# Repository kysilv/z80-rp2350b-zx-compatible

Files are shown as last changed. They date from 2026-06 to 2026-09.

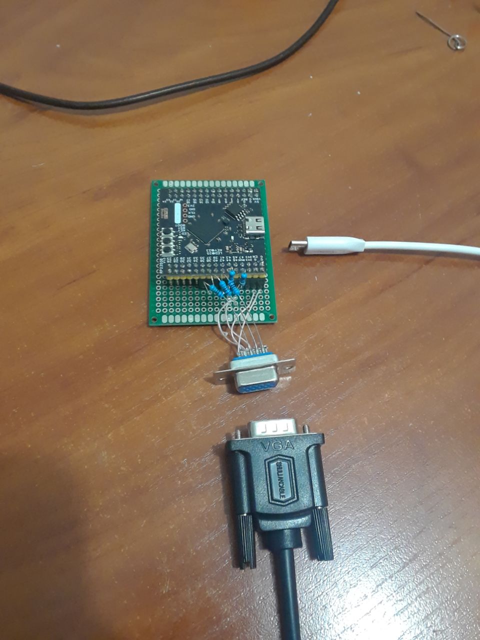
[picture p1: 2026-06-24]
photos/vga_test.jpg

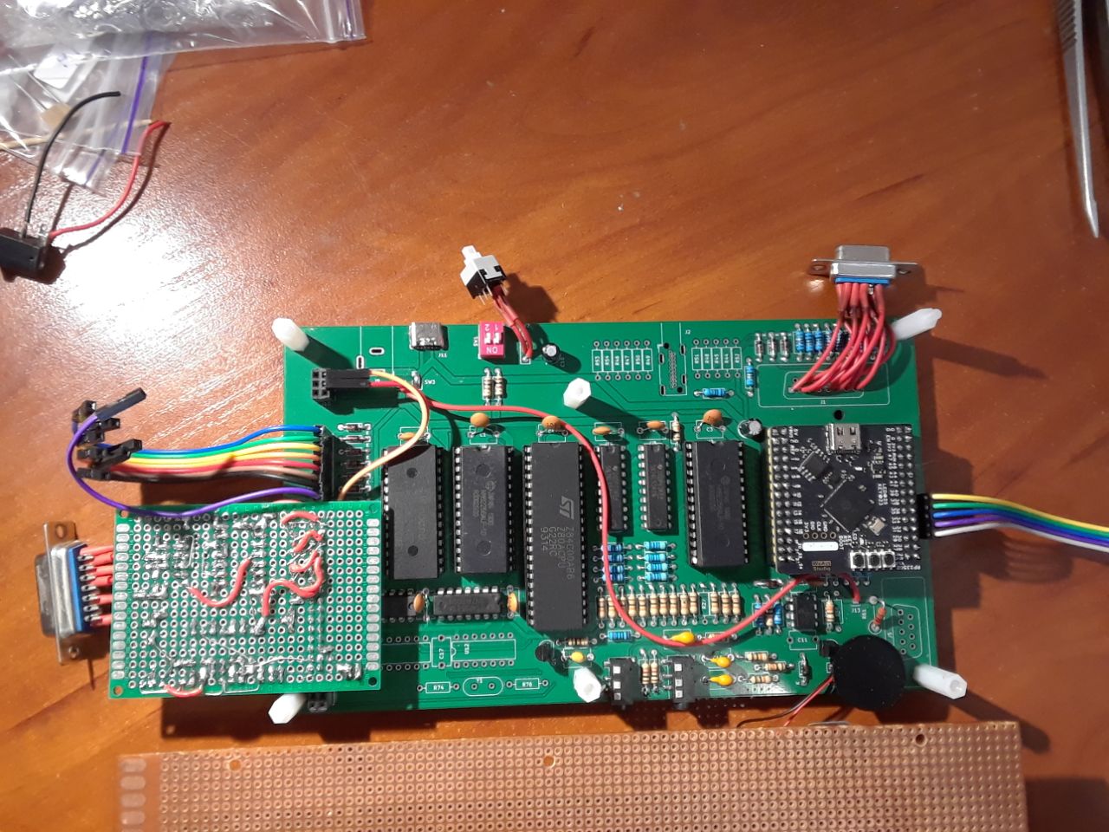
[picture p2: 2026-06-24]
photos/9_Joystick_da15_installed.jpg

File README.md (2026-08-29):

# z80-rp2350b-zx-compatible
This is a retrocomputer compatible with ZX Spectrum and based on real Z80 + discrete RAM/ROM + rp2350b to cover ULA functionality programmatically.

## Specification:

**CPU**: Z84C00AB6 Z80A CPU DIP-40

**ROM**: W27c512-45z DIP-28

**RAM**: 2xHM62256ALP-10 DIP-28

**ULA**: WeAct RP2350B Core board

**Video**: VGA (DE-15) and DVI over HDMI connector, 720x576p emulating Spectrum PAL resolution.

**Audio**: Speaker on board

**Cassette interface**: Jack 3.5mm for smartphone headset jack

**Keyboard**: Handmade

**Joystick**: 
  1. Retro DA-15 GamePort joystick interface connected to expansion connector, emulating Kempston port 1F.
  2. Sinclair Joystick 1 in parallel to keyboard 6-0 (connector not soldered yet).

## Folders:

**firmware**: Source code for rp2350b covering ULA functionality (C + PIO ASM)

**hardware**: Pictures of schematic and pcbs, KiCAD projects of the computer and Joystick interface. There are pictures of the first version with a lot of fixes. 

**photos**: Photos of the device in process of tuning and some "screenshots".

Press: https://hackaday.com/2026/07/13/its-a-spectrum-with-an-rp2350-ula/

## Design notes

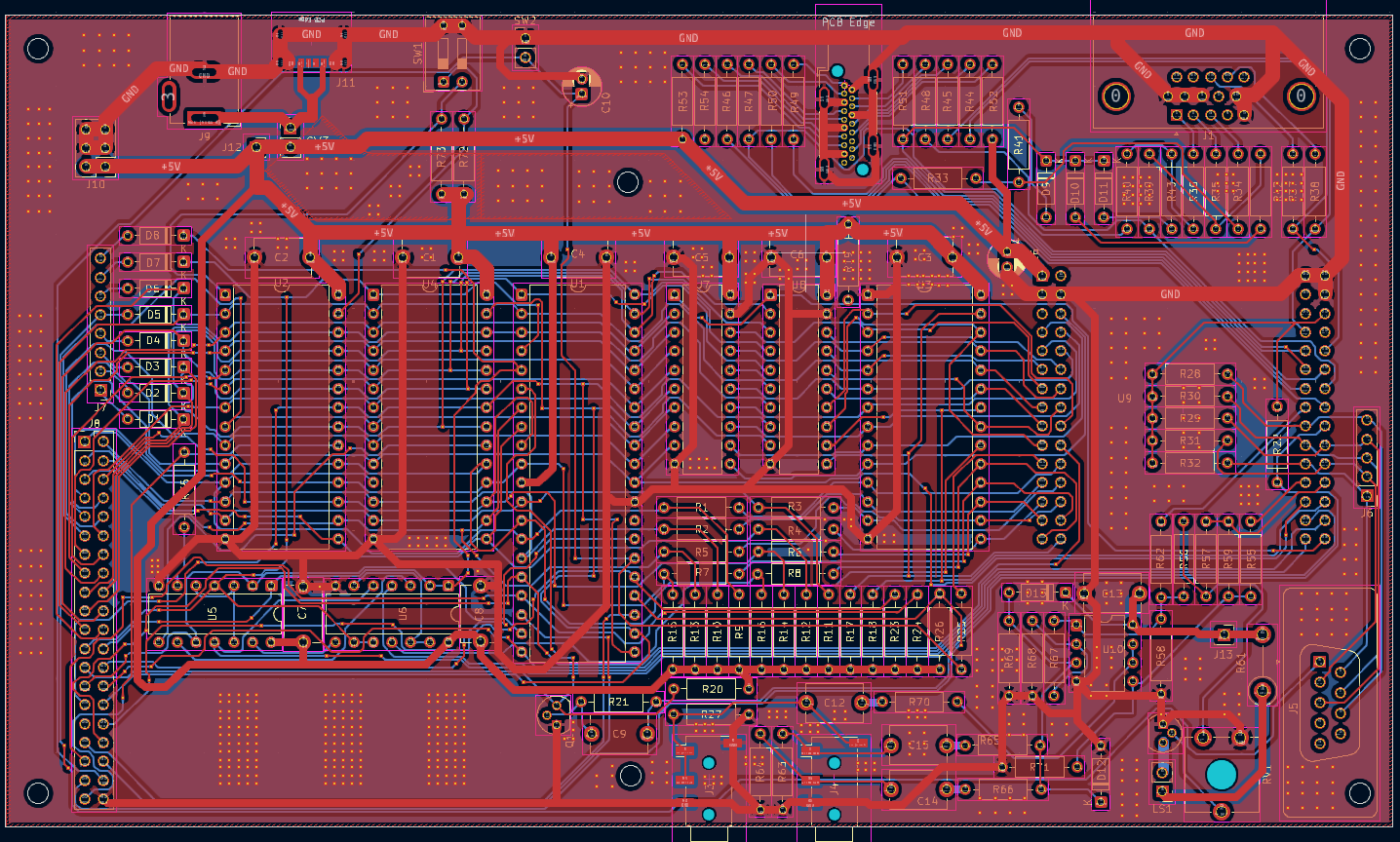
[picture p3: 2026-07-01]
hardware/3_5_pcb_new.png

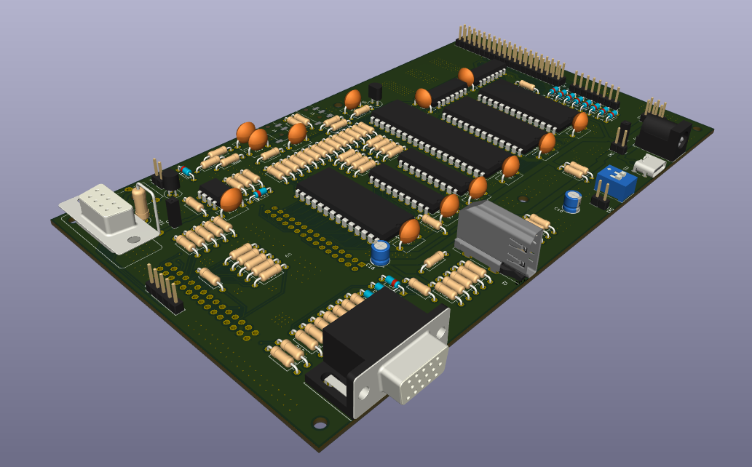
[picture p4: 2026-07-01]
hardware/3_6_3d_View.png

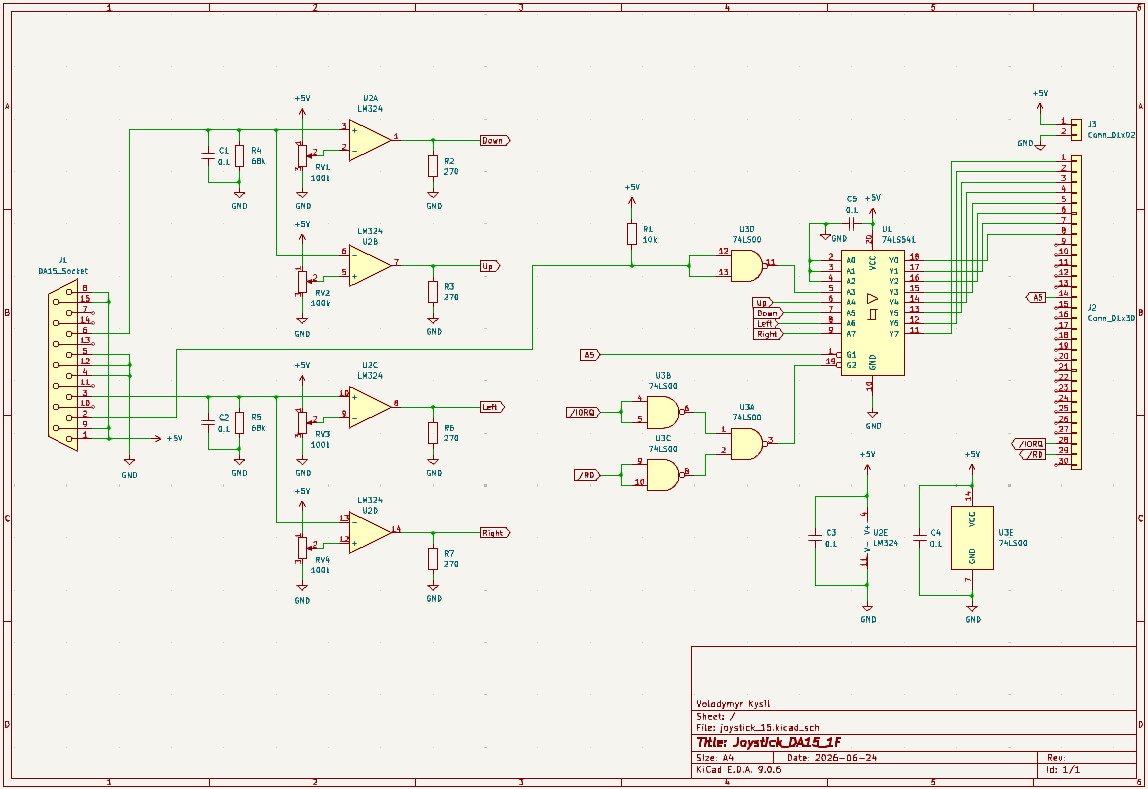
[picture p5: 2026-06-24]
hardware/4_Joystick_DA15_1F_schematic.png

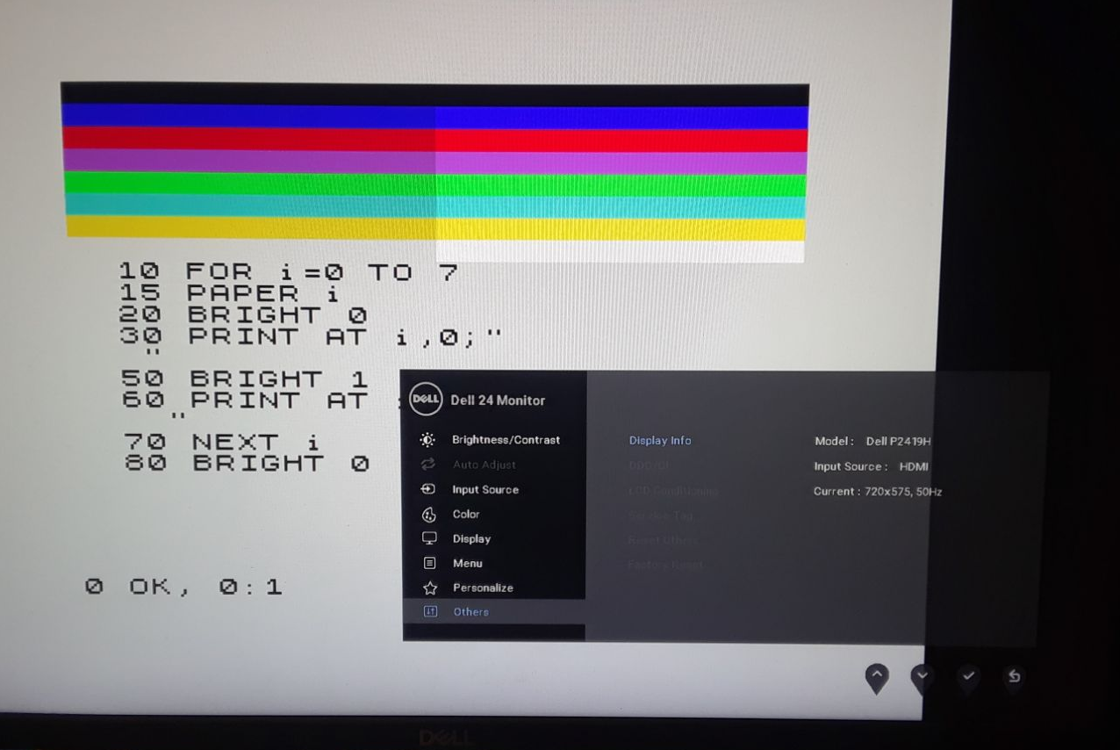
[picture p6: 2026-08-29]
hardware/7_HDMI_colors.png

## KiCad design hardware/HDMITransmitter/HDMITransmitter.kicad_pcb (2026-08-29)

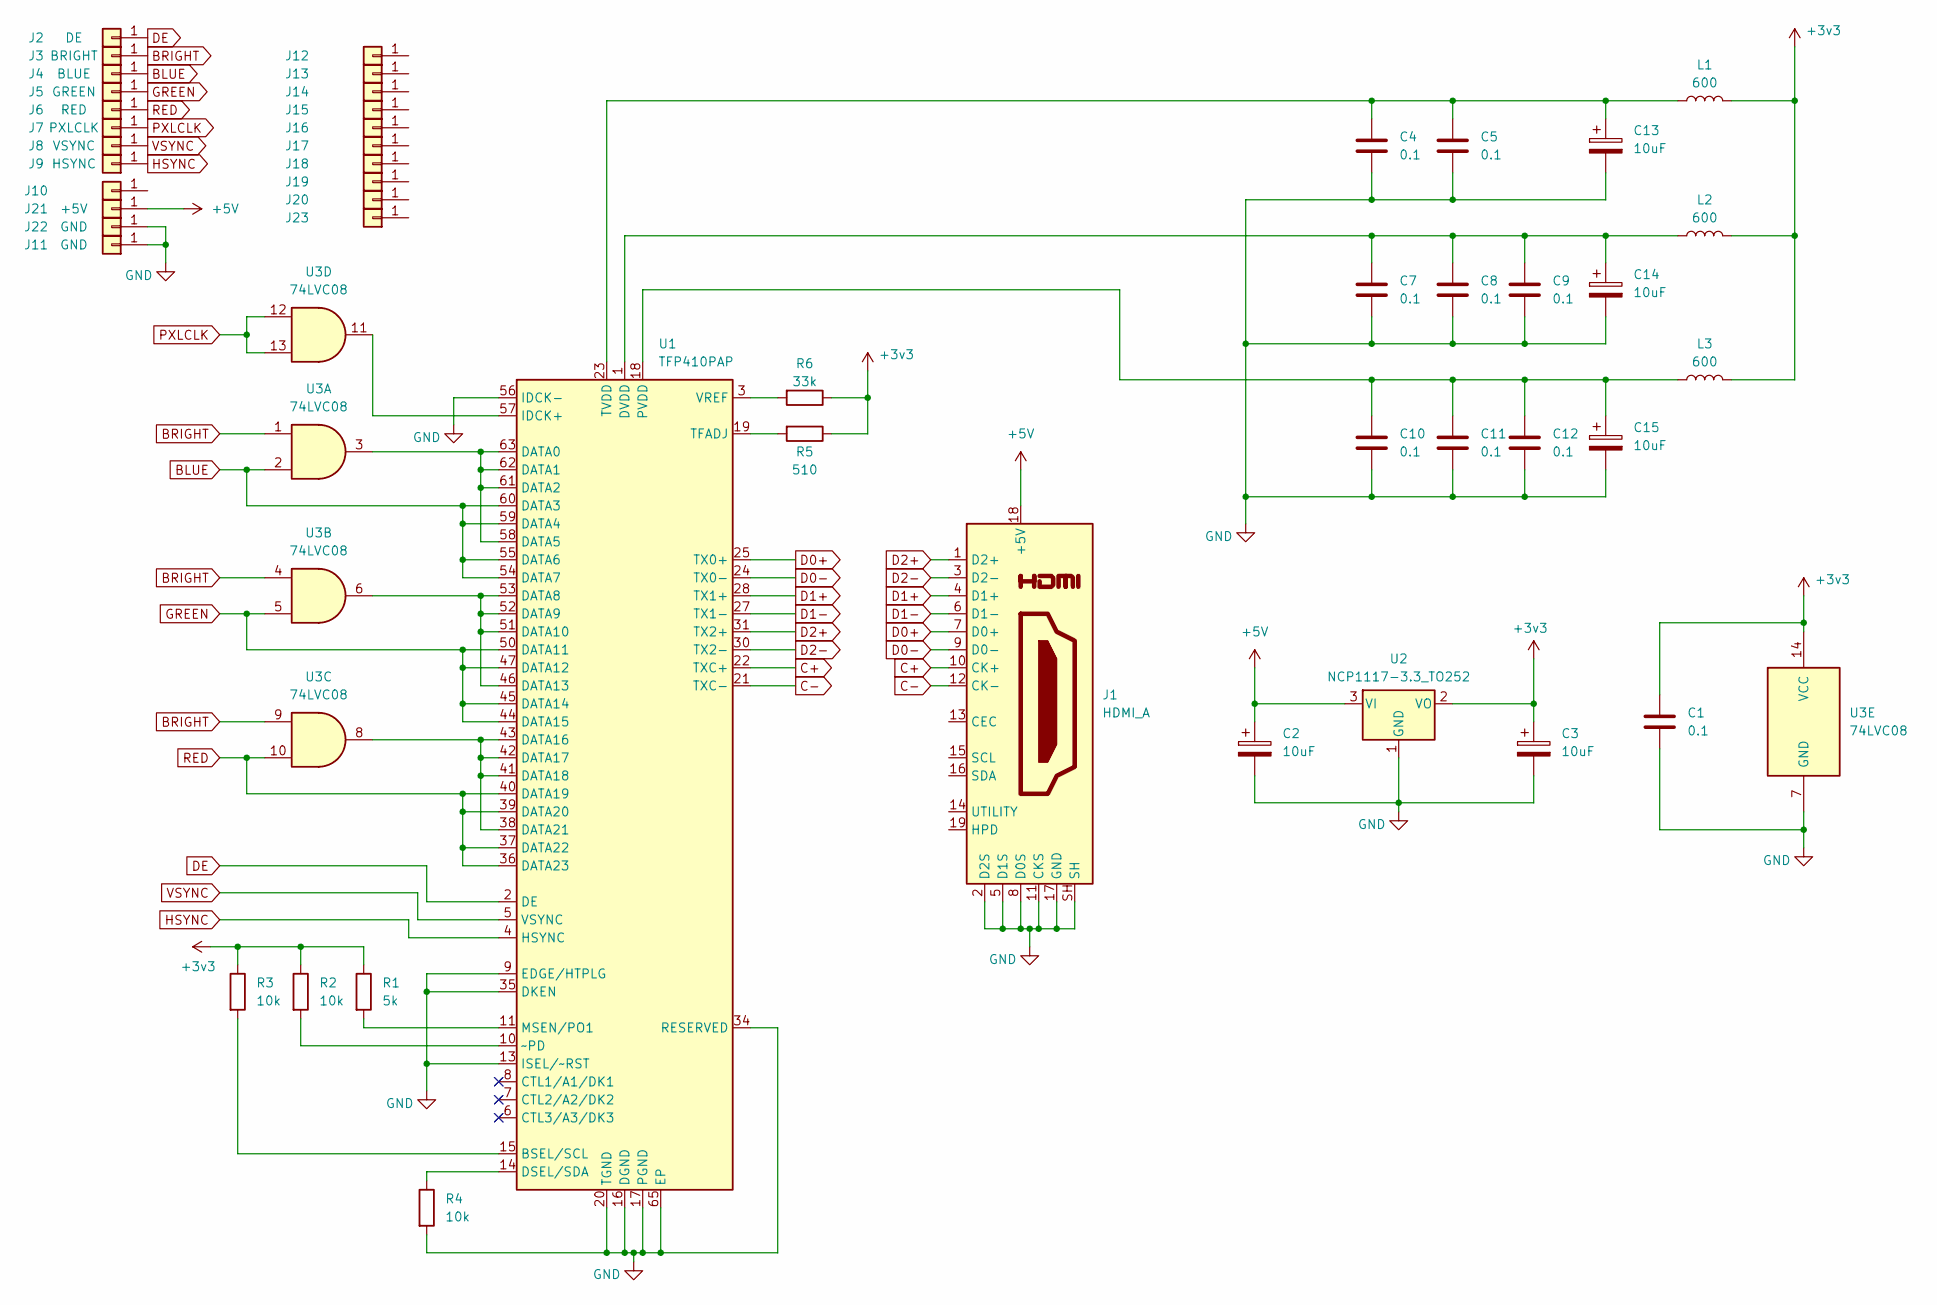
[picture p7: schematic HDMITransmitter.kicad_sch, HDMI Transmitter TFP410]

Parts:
C1, C4, C5, C7, C8, C9, C10, C11, C12: 0.1; C_0603_1608Metric_Pad1.08x0.95mm_HandSolder
C2, C3, C13, C14, C15: 10uF; CP_EIA-3216-18_Kemet-A_HandSolder
J1: HDMI_A; HDMI_A_Molex_208658-1001_Horizontal
J2: DE; Pin_D1.0mm_L10.0mm
J3: BRIGHT; Pin_D1.0mm_L10.0mm
J4: BLUE; Pin_D1.0mm_L10.0mm
J5: GREEN; Pin_D1.0mm_L10.0mm
J6: RED; Pin_D1.0mm_L10.0mm
J7: PXLCLK; Pin_D1.0mm_L10.0mm
J8: VSYNC; Pin_D1.0mm_L10.0mm
J9: HSYNC; Pin_D1.0mm_L10.0mm
J10, J12, J13, J14, J15, J16, J17, J18, J19, J20, J23: Pin_D1.0mm_L10.0mm
J11, J22: GND; Pin_D1.0mm_L10.0mm
J21: +5V; Pin_D1.0mm_L10.0mm
L1, L2, L3: 600; L_0603_1608Metric_Pad1.05x0.95mm_HandSolder
R1: 5k; R_0603_1608Metric_Pad0.98x0.95mm_HandSolder
R2, R3, R4: 10k; R_0603_1608Metric_Pad0.98x0.95mm_HandSolder
R5: 510; R_0603_1608Metric_Pad0.98x0.95mm_HandSolder
R6: 33k; R_0603_1608Metric_Pad0.98x0.95mm_HandSolder
U1: TFP410PAP; Texas_TQFP-64-1EP_10x10mm_P0.5mm_EP8x8mm_Mask5x5mm_ThermalV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
U2: NCP1117-3.3_TO252; TO-252-2
U3: 74LVC08; SOIC-14_3.9x8.7mm_P1.27mm

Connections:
+3v3: C1.1, C3.1, L1.2, L2.2, L3.2, R1.1, R2.1, R3.1, R5.1, R6.1, U2.2 (VO), U3.14 (VCC)
+5V: C2.1, J1.18 (+5V), J21.1, U2.3 (VI)
BLUE: J4.1, U1.54 (DATA7), U1.55 (DATA6), U1.59 (DATA4), U1.60 (DATA3), U3.2
BRIGHT: J3.1, U3.1, U3.4, U3.9
C+: J1.10 (CK+), U1.22 (TXC+)
C-: J1.12 (CK-), U1.21 (TXC-)
D0+: J1.7 (D0+), U1.25 (TX0+)
D0-: J1.9 (D0-), U1.24 (TX0-)
D1+: J1.4 (D1+), U1.28 (TX1+)
D1-: J1.6 (D1-), U1.27 (TX1-)
D2+: J1.1 (D2+), U1.31 (TX2+)
D2-: J1.3 (D2-), U1.30 (TX2-)
DE: J2.1, U1.2 (DE)
GND: C1.2, C2.2, C3.2, C4.2, C5.2, C7.2, C8.2, C9.2, C10.2, C11.2, C12.2, C13.2, C14.2, C15.2, J1.2 (D2S), J1.5 (D1S), J1.8 (D0S), J1.11 (CKS), J1.17 (GND), J1.SH, J11.1, J22.1, R4.2, U1.9 (EDGE/HTPLG), U1.13 (ISEL/~RST), U1.16 (DGND), U1.17 (PGND), U1.20 (TGND), U1.26 (TGND), U1.32 (TGND), U1.34 (RESERVED), U1.35 (DKEN), U1.48 (DGND), U1.56 (IDCK-), U1.64 (DGND), U1.65 (EP), U2.1 (GND), U3.7 (GND)
GREEN: J5.1, U1.44 (DATA15), U1.45 (DATA14), U1.47 (DATA12), U1.50 (DATA11), U3.5
HSYNC: J9.1, U1.4 (HSYNC)
unnamed: C4.1, C5.1, C13.1, L1.1, U1.23 (TVDD), U1.29 (TVDD)
unnamed: C7.1, C8.1, C9.1, C14.1, L2.1, U1.1 (DVDD), U1.12 (DVDD), U1.33 (DVDD)
unnamed: R3.2, U1.15 (BSEL/SCL)
unnamed: U1.58 (DATA5), U1.61 (DATA2), U1.62 (DATA1), U1.63 (DATA0), U3.3
unnamed: U1.46 (DATA13), U1.51 (DATA10), U1.52 (DATA9), U1.53 (DATA8), U3.6
unnamed: U1.38 (DATA21), U1.41 (DATA18), U1.42 (DATA17), U1.43 (DATA16), U3.8
unnamed: R4.1, U1.14 (DSEL/SDA)
unnamed: U1.57 (IDCK+), U3.11
unnamed: R1.2, U1.11 (MSEN/PO1)
unnamed: C10.1, C11.1, C12.1, C15.1, L3.1, U1.18 (PVDD)
unnamed: R5.2, U1.19 (TFADJ)
unnamed: R6.2, U1.3 (VREF)
unnamed: R2.2, U1.10 (~PD)
PXLCLK: J7.1, U3.12, U3.13
RED: J6.1, U1.36 (DATA23), U1.37 (DATA22), U1.39 (DATA20), U1.40 (DATA19), U3.10
VSYNC: J8.1, U1.5 (VSYNC)

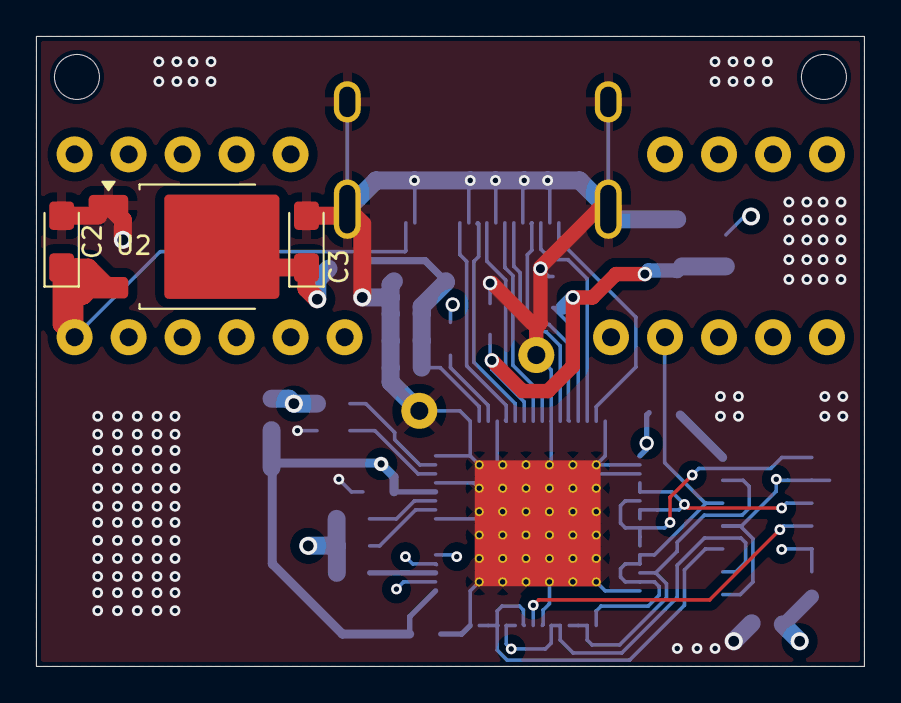
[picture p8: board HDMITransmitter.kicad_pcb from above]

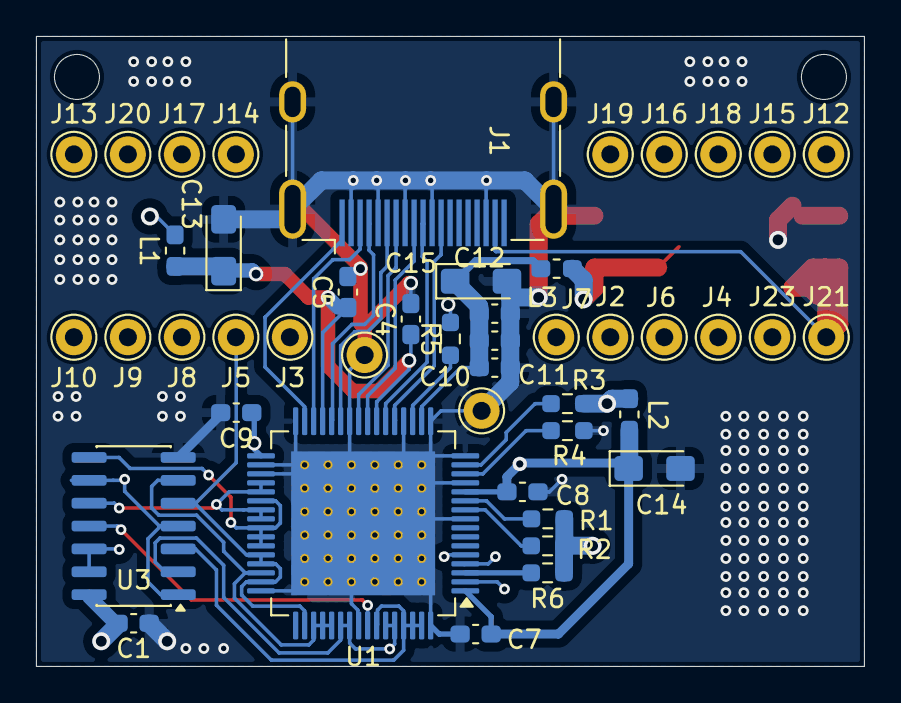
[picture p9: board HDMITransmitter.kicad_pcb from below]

Board: 4 copper layers, 46.0 x 35.0 mm, 49 parts (46 on the bottom side), 32 nets.

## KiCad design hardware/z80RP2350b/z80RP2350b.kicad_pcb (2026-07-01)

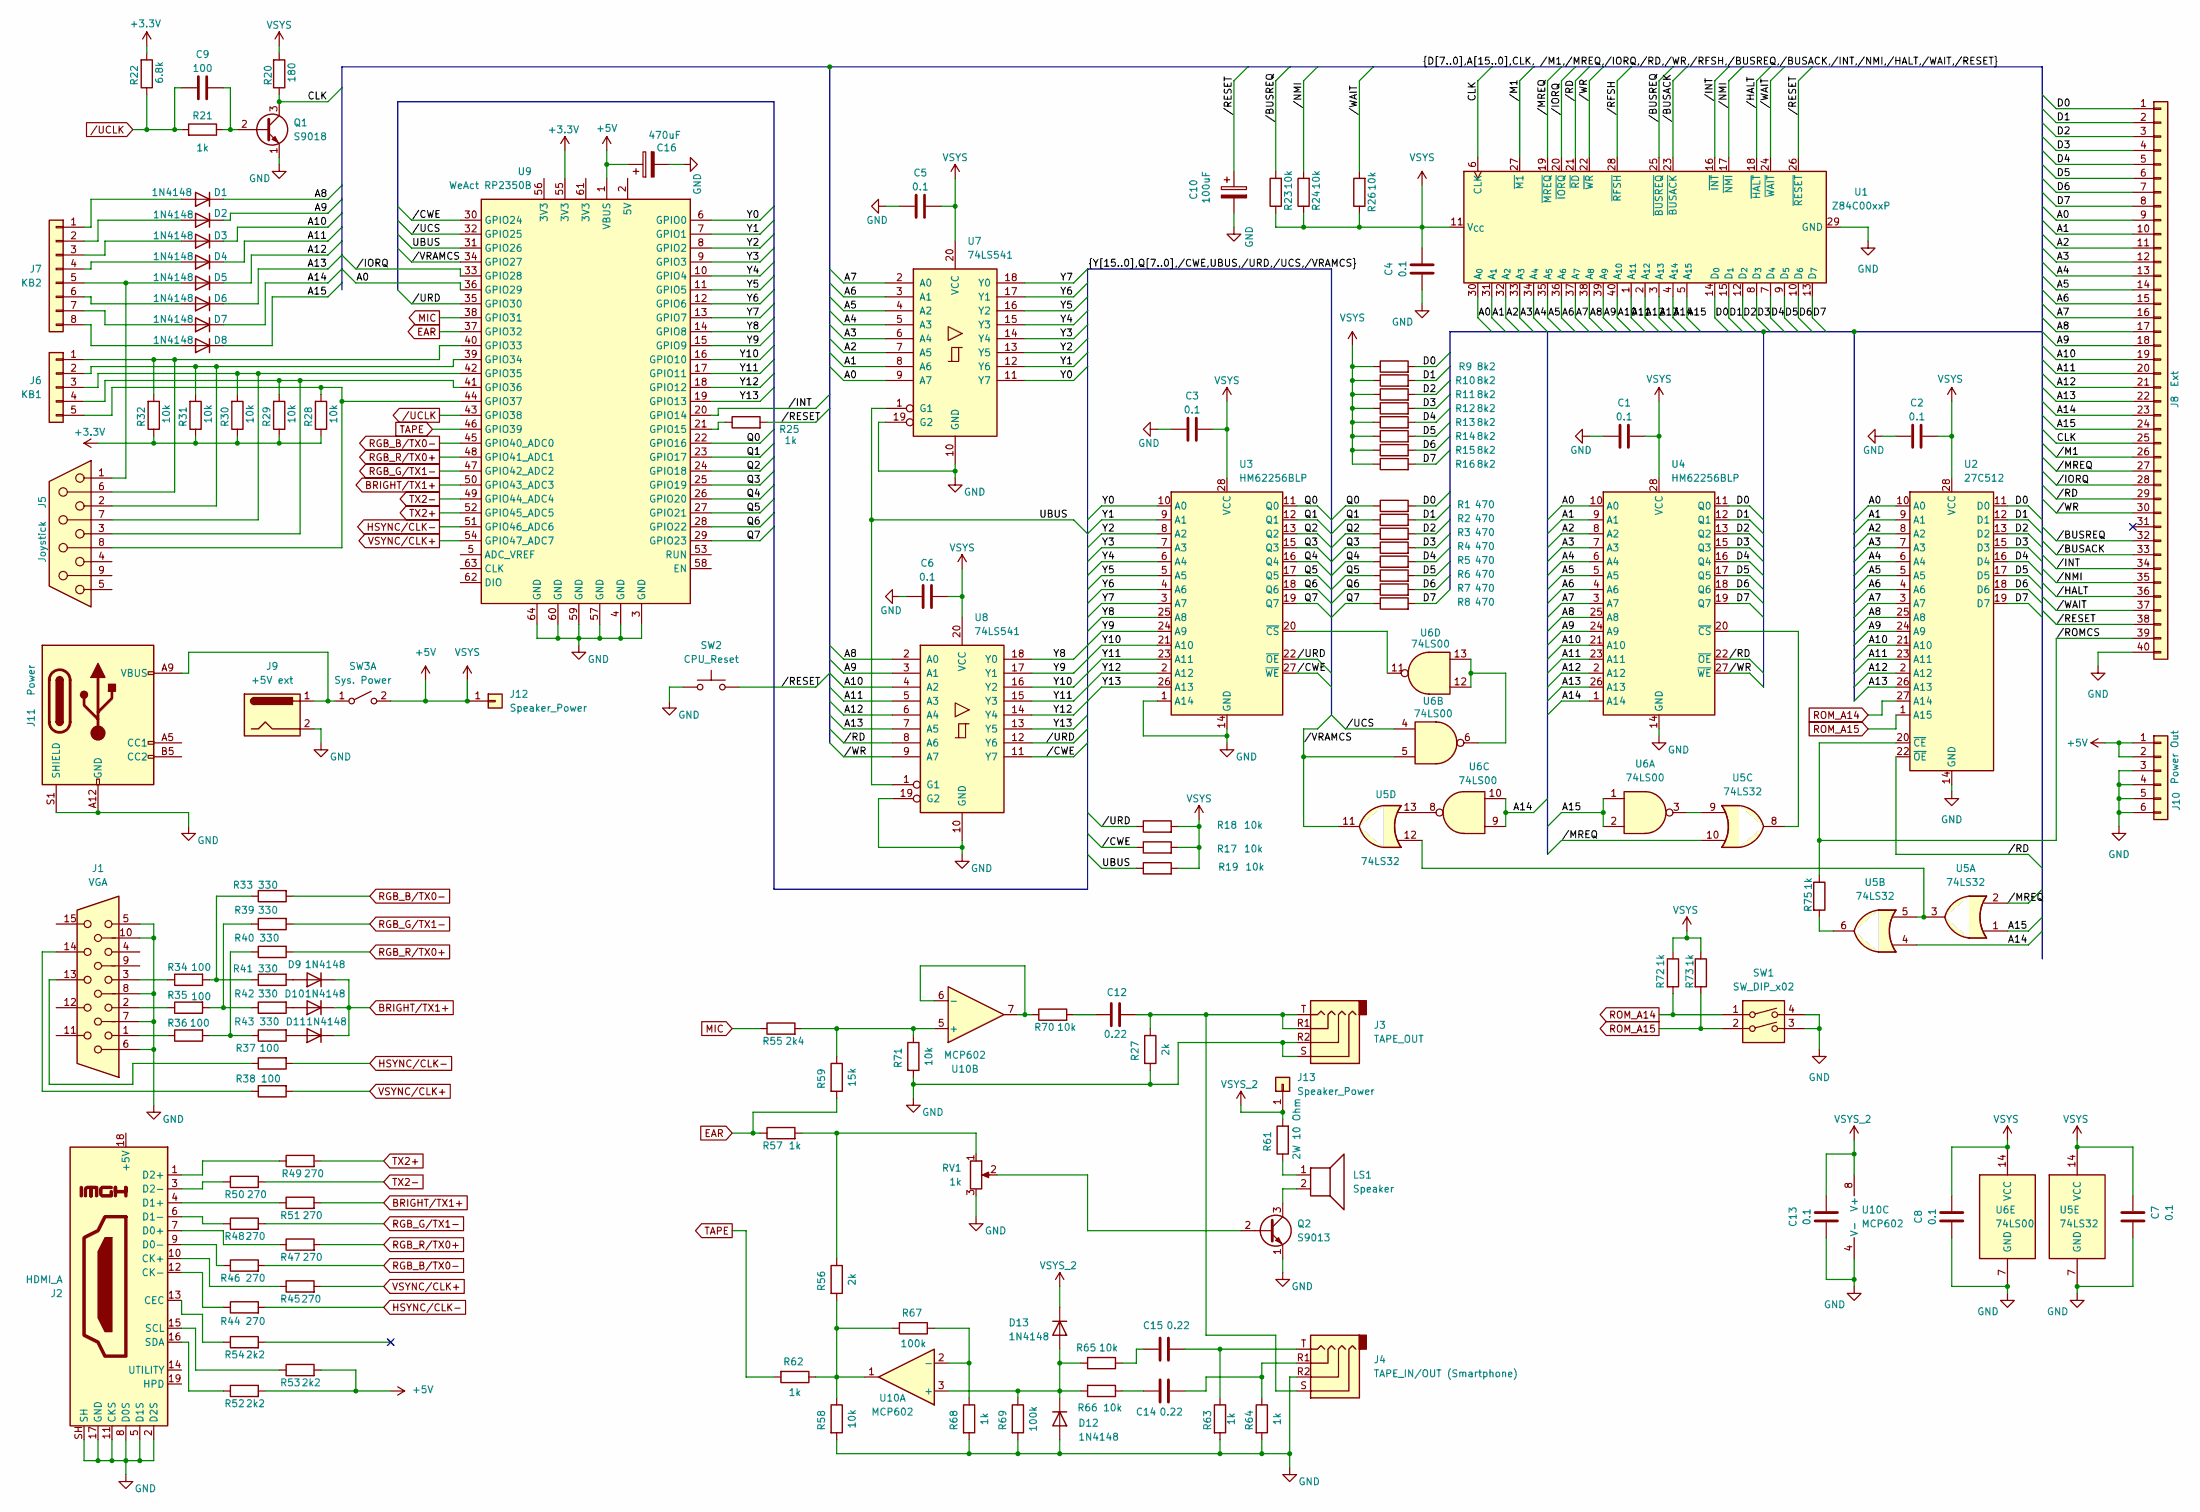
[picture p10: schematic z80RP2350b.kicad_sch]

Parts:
C1, C2, C3, C4, C5, C6, C7, C8, C13: 0.1; C_Disc_D7.5mm_W5.0mm_P7.50mm
C9: 100; C_Disc_D7.5mm_W5.0mm_P7.50mm
C10: 100uF; CP_Radial_D5.0mm_P2.00mm
C12, C14, C15: 0.22; C_Disc_D7.5mm_W5.0mm_P7.50mm
C16: 470uF; CP_Radial_D5.0mm_P2.00mm
D1, D2, D3, D4, D5, D6, D7, D8, D9, D10, D11, D12, D13: 1N4148; D_DO-35_SOD27_P7.62mm_Horizontal
J1: VGA; DSUB-15-HD_Socket_Horizontal_P2.29x2.54mm_EdgePinOffset8.35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
J2: HDMI_A; HDMI_A_Kycon_KDMIX-SL1-NS-WS-B15_VerticalRightAngle
J3: TAPE_OUT; Jack_3.5mm_PJ320D_Horizontal
J4: TAPE_IN/OUT (Smartphone); Jack_3.5mm_PJ320D_Horizontal
J5: Joystick; DSUB-9_Socket_Vertical_P2.77x2.84mm
J6: KB1; PinHeader_1x05_P2.54mm_Vertical
J7: KB2; PinHeader_1x08_P2.54mm_Vertical
J8: Ext; PinHeader_2x20_P2.54mm_Vertical
J9: +5V ext; BarrelJack_GCT_DCJ200-10-A_Horizontal
J10: Power Out; PinHeader_2x03_P2.54mm_Vertical
J11: Power; USB_C_Receptacle_GCT_USB4125-xx-x_6P_TopMnt_Horizontal
J12, J13: Speaker_Power; PinSocket_1x01_P2.54mm_Vertical
LS1: Speaker; PinHeader_1x02_P2.54mm_Vertical
Q1: S9018; TO-92
Q2: S9013; TO-92
R1, R2, R3, R4, R5, R6, R7, R8: 470; R_Axial_DIN0207_L6.3mm_D2.5mm_P10.16mm_Horizontal
R9, R10, R11, R12, R13, R14, R15, R16: 8k2; R_Axial_DIN0207_L6.3mm_D2.5mm_P10.16mm_Horizontal
R17, R18, R19, R23, R24, R26, R28, R29, R30, R31, R32, R58, R65, R66, R70, R71: 10k; R_Axial_DIN0207_L6.3mm_D2.5mm_P10.16mm_Horizontal
R20: 180; R_Axial_DIN0207_L6.3mm_D2.5mm_P10.16mm_Horizontal
R21, R25, R57, R62, R63, R64, R68, R72, R73, R75: 1k; R_Axial_DIN0207_L6.3mm_D2.5mm_P10.16mm_Horizontal
R22: 6.8k; R_Axial_DIN0207_L6.3mm_D2.5mm_P10.16mm_Horizontal
R27, R56: 2k; R_Axial_DIN0207_L6.3mm_D2.5mm_P10.16mm_Horizontal
R33, R39, R40, R41, R42, R43: 330; R_Axial_DIN0207_L6.3mm_D2.5mm_P10.16mm_Horizontal
R34, R35, R36, R37, R38: 100; R_Axial_DIN0207_L6.3mm_D2.5mm_P10.16mm_Horizontal
R44, R45, R46, R47, R48, R49, R50, R51: 270; R_Axial_DIN0207_L6.3mm_D2.5mm_P10.16mm_Horizontal
R52, R53, R54: 2k2; R_Axial_DIN0207_L6.3mm_D2.5mm_P10.16mm_Horizontal
R55: 2k4; R_Axial_DIN0207_L6.3mm_D2.5mm_P10.16mm_Horizontal
R59: 15k; R_Axial_DIN0207_L6.3mm_D2.5mm_P10.16mm_Horizontal
R61: 2W 10 Ohm; R_Axial_DIN0411_L9.9mm_D3.6mm_P7.62mm_Vertical
R67, R69: 100k; R_Axial_DIN0207_L6.3mm_D2.5mm_P10.16mm_Horizontal
RV1: 1k; Potentiometer_ACP_CA9-V10_Vertical_Hole
SW1: SW_DIP_x02; SW_DIP_SPSTx02_Slide_9.78x7.26mm_W7.62mm_P2.54mm
SW2: CPU_Reset; PinHeader_1x02_P2.54mm_Vertical
SW3: Sys. Power; PinHeader_1x02_P2.54mm_Vertical
U1: Z84C00xxP; DIP-40_W15.24mm
U2: 27C512; DIP-28_W15.24mm
U3, U4: HM62256BLP; DIP-28_W15.24mm
U5: 74LS32; DIP-14_W7.62mm
U6: 74LS00; DIP-14_W7.62mm
U7, U8: 74LS541; DIP-20_W7.62mm
U9: WeAct RP2350B; WeAct_RP2350b
U10: MCP602; DIP-8_W7.62mm

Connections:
+3.3V: R22.2, R28.1, R29.1, R30.1, R31.1, R32.1, U9.55 (3V3)
+5V: C1.1, C2.1, C3.1, C4.1, C5.1, C6.1, C7.1, C8.1, C16.1, J10.1, J10.2, J12.1, R9.1, R10.1, R11.1, R12.1, R13.1, R14.1, R15.1, R16.1, R17.2, R18.2, R19.2, R20.2, R23.1, R24.1, R26.1, R52.2, R53.2, R72.1, R73.1, SW3.2 (B), U1.11 (V_{CC}), U2.28 (VCC), U3.28 (VCC), U4.28 (VCC), U5.14 (VCC), U6.14 (VCC), U7.20 (VCC), U8.20 (VCC), U9.1 (VBUS)
/A0: J8.9, U1.30 (A_{0}), U2.10 (A0), U4.10 (A0), U7.9 (A7), U9.36 (GPIO29)
/A1: J8.10, U1.31 (A_{1}), U2.9 (A1), U4.9 (A1), U7.8 (A6)
/A2: J8.11, U1.32 (A_{2}), U2.8 (A2), U4.8 (A2), U7.7 (A5)
/A3: J8.12, U1.33 (A_{3}), U2.7 (A3), U4.7 (A3), U7.6 (A4)
/A4: J8.13, U1.34 (A_{4}), U2.6 (A4), U4.6 (A4), U7.5 (A3)
/A5: J8.14, U1.35 (A_{5}), U2.5 (A5), U4.5 (A5), U7.4 (A2)
/A6: J8.15, U1.36 (A_{6}), U2.4 (A6), U4.4 (A6), U7.3 (A1)
/A7: J8.16, U1.37 (A_{7}), U2.3 (A7), U4.3 (A7), U7.2 (A0)
/A8: D1.1 (K), J8.17, U1.38 (A_{8}), U2.25 (A8), U4.25 (A8), U8.2 (A0)
/A9: D2.1 (K), J8.18, U1.39 (A_{9}), U2.24 (A9), U4.24 (A9), U8.3 (A1)
/A10: D3.1 (K), J8.19, U1.40 (A_{10}), U2.21 (A10), U4.21 (A10), U8.4 (A2)
/A11: D4.1 (K), J8.20, U1.1 (A_{11}), U2.23 (A11), U4.23 (A11), U8.5 (A3)
/A12: D5.1 (K), J8.21, U1.2 (A_{12}), U2.2 (A12), U4.2 (A12), U8.6 (A4)
/A13: D6.1 (K), J8.22, U1.3 (A_{13}), U2.26 (A13), U4.26 (A13), U8.7 (A5)
/A14: D7.1 (K), J8.23, U1.4 (A_{14}), U4.1 (A14), U5.4, U6.9, U6.10
/A15: D8.1 (K), J8.24, U1.5 (A_{15}), U5.1, U6.1, U6.2
/CLK: J8.25, Q1.3 (C), R20.1, U1.6 (CLK)
/D0: J8.1, R1.2, R9.2, U1.14 (D_{0}), U2.11 (D0), U4.11 (Q0)
/D1: J8.2, R2.2, R10.2, U1.15 (D_{1}), U2.12 (D1), U4.12 (Q1)
/D2: J8.3, R3.2, R11.2, U1.12 (D_{2}), U2.13 (D2), U4.13 (Q2)
/D3: J8.4, R4.2, R12.2, U1.8 (D_{3}), U2.15 (D3), U4.15 (Q3)
/D4: J8.5, R5.2, R13.2, U1.7 (D_{4}), U2.16 (D4), U4.16 (Q4)
/D5: J8.6, R6.2, R14.2, U1.9 (D_{5}), U2.17 (D5), U4.17 (Q5)
/D6: J8.7, R7.2, R15.2, U1.10 (D_{6}), U2.18 (D6), U4.18 (Q6)
/D7: J8.8, R8.2, R16.2, U1.13 (D_{7}), U2.19 (D7), U4.19 (Q7)
/Q0: R1.1, U3.11 (Q0), U9.22 (GPIO16)
/Q1: R2.1, U3.12 (Q1), U9.23 (GPIO17)
/Q2: R3.1, U3.13 (Q2), U9.24 (GPIO18)
/Q3: R4.1, U3.15 (Q3), U9.25 (GPIO19)
/Q4: R5.1, U3.16 (Q4), U9.26 (GPIO20)
/Q5: R6.1, U3.17 (Q5), U9.27 (GPIO21)
/Q6: R7.1, U3.18 (Q6), U9.28 (GPIO22)
/Q7: R8.1, U3.19 (Q7), U9.29 (GPIO23)
/UBUS: R19.1, U7.1 (G1), U8.1 (G1), U9.31 (GPIO26)
/Y0: U3.10 (A0), U7.11 (Y7), U9.6 (GPIO0)
/Y1: U3.9 (A1), U7.12 (Y6), U9.7 (GPIO1)
/Y2: U3.8 (A2), U7.13 (Y5), U9.8 (GPIO2)
/Y3: U3.7 (A3), U7.14 (Y4), U9.9 (GPIO3)
/Y4: U3.6 (A4), U7.15 (Y3), U9.10 (GPIO4)
/Y5: U3.5 (A5), U7.16 (Y2), U9.11 (GPIO5)
/Y6: U3.4 (A6), U7.17 (Y1), U9.12 (GPIO6)
/Y7: U3.3 (A7), U7.18 (Y0), U9.13 (GPIO7)
/Y8: U3.25 (A8), U8.18 (Y0), U9.14 (GPIO8)
/Y9: U3.24 (A9), U8.17 (Y1), U9.15 (GPIO9)
/Y10: U3.21 (A10), U8.16 (Y2), U9.16 (GPIO10)
/Y11: U3.23 (A11), U8.15 (Y3), U9.17 (GPIO11)
/Y12: U3.2 (A12), U8.14 (Y4), U9.18 (GPIO12)
/Y13: U3.26 (A13), U8.13 (Y5), U9.19 (GPIO13)
//BUSACK: J8.33, U1.23 (~BUSACK)
//BUSREQ: J8.32, R23.2, U1.25 (~BUSREQ)
//CWE: R17.1, U3.27 (~WE), U8.11 (Y7), U9.30 (GPIO24)
//HALT: J8.36, U1.18 (~HALT)
//INT: J8.34, U1.16 (~INT), U9.20 (GPIO14)
//IORQ: J8.28, U1.20 (~IORQ), U9.33 (GPIO28)
//M1: J8.26, U1.27 (~M1)
//MREQ: J8.27, U1.19 (~MREQ), U5.2, U5.10
//NMI: J8.35, R24.2, U1.17 (~NMI)
//RD: J8.29, U1.21 (~RD), U2.22 (~OE), U4.22 (~OE), U8.8 (A6)
//RESET: C10.1, J8.38, R25.2, SW2.2, U1.26 (~RESET)
//RFSH: U1.28 (~RFSH)
//ROMCS: J8.39, R75.1, U2.20 (~CE)
//UCS: U6.4, U9.32 (GPIO25)
//URD: R18.1, U3.22 (~OE), U8.12 (Y6), U9.35 (GPIO30)
//VRAMCS: U5.11, U6.5, U9.34 (GPIO27)
//WAIT: J8.37, R26.2, U1.24 (~WAIT)
//WR: J8.30, U1.22 (~WR), U4.27 (~WE), U8.9 (A7)
BRIGHT/TX1+: D9.1 (K), D10.1 (K), D11.1 (K), R51.2, U9.50 (GPIO43_ADC3)
EAR: R57.1, R59.2, U9.37 (GPIO32)
GND: C1.2, C2.2, C3.2, C4.2, C5.2, C6.2, C7.2, C8.2, C10.2, C13.2, C16.2, D12.2 (A), J1.5, J1.6, J1.7, J1.8, J1.10, J2.2 (D2S), J2.5 (D1S), J2.8 (D0S), J2.11 (CKS), J2.17 (GND), J2.SH, J3.R2, J3.S, J4.R2, J8.40, J9.2, J10.3, J10.4, J10.5, J10.6, J11.A12 (GND), J11.B12 (GND), J11.S1 (SHIELD), Q1.1 (E), Q2.1 (E), R27.2, R58.2, R63.2, R64.2, R68.2, R69.2, R71.2, RV1.3, SW1.3, SW1.4, SW2.1, U1.29 (GND), U2.14 (GND), U3.1 (A14), U3.14 (GND), U4.14 (GND), U5.7 (GND), U6.7 (GND), U7.10 (GND), U7.19 (G2), U8.10 (GND), U8.19 (G2), U9.3 (GND), U9.4 (GND), U9.57 (GND), U9.59 (GND), U9.60 (GND), U9.64 (GND), U10.4 (V-)
HSYNC/CLK-: R37.2, R44.2, U9.51 (GPIO46_ADC6)
MIC: R55.1, U9.38 (GPIO31)
unnamed: C12.1, R70.2
unnamed: C12.2, J3.R1, J3.T, J4.S, R27.1
unnamed: C14.1, R66.1
unnamed: C14.2, J4.R1, R64.1
unnamed: C15.1, R65.1
unnamed: C15.2, J4.T, R63.1
unnamed: D1.2 (A), J7.1
unnamed: D2.2 (A), J7.2
unnamed: D3.2 (A), J7.3
unnamed: D4.2 (A), J7.4
unnamed: D5.2 (A), J5.1, J7.5
unnamed: D6.2 (A), J7.6
unnamed: D7.2 (A), J7.7
unnamed: D8.2 (A), J7.8
unnamed: D9.2 (A), R41.2
unnamed: D10.2 (A), R42.2
unnamed: D11.2 (A), R43.2
unnamed: D12.1 (K), D13.2 (A), R65.2, R66.2, R69.1, U10.3 (+)
unnamed: J1.1, R36.1
unnamed: J1.2, R35.1
unnamed: J1.3, R34.1
unnamed: J1.13, R37.1
unnamed: J1.14, R38.1
unnamed: J2.13 (CEC), R54.1
unnamed: J2.10 (CK+), R45.1
unnamed: J2.12 (CK-), R44.1
unnamed: J2.7 (D0+), R47.1
unnamed: J2.9 (D0-), R46.1
unnamed: J2.4 (D1+), R51.1
unnamed: J2.6 (D1-), R48.1
unnamed: J2.1 (D2+), R49.1
unnamed: J2.3 (D2-), R50.1
unnamed: J2.15 (SCL), R53.1
unnamed: J2.16 (SDA), R52.1
unnamed: J5.6, J6.1, R32.2, U9.40 (GPIO33)
unnamed: J5.2, J6.2, R31.2, U9.39 (GPIO34)
unnamed: J5.7, J6.3, R30.2, U9.42 (GPIO35)
unnamed: J5.3, J6.4, R29.2, U9.41 (GPIO36)
unnamed: J5.8, J6.5, R28.2, U9.44 (GPIO37)
unnamed: LS1.1, R61.1
unnamed: C9.2, Q1.2 (B), R21.1
unnamed: Q2.2 (B), RV1.2
unnamed: LS1.2, Q2.3 (C)
unnamed: R33.1, R34.2, R41.1
unnamed: R35.2, R39.1, R42.1
unnamed: R36.2, R40.1, R43.1
unnamed: R56.1, R57.2, RV1.1
unnamed: R56.2, R58.1, R62.1, R67.2, U10.1
unnamed: R75.2, U5.6
unnamed: J9.1, J11.A9 (VBUS), J11.B9 (VBUS), SW3.1 (A)
unnamed: U3.20 (~CS), U6.11
unnamed: U4.20 (~CS), U5.8
unnamed: U5.9, U6.3
unnamed: U5.3, U5.5, U5.12
unnamed: U5.13, U6.8
unnamed: U6.6, U6.12, U6.13
unnamed: R25.1, U9.21 (GPIO15)
unnamed: R67.1, R68.1, U10.2 (-)
unnamed: R55.2, R59.1, R71.1, U10.5 (+)
unnamed: R70.1, U10.6 (-), U10.7
RGB_B/TX0-: R33.2, R46.2, U9.45 (GPIO40_ADC0)
RGB_G/TX1-: R39.2, R48.2, U9.47 (GPIO42_ADC2)
RGB_R/TX0+: R40.2, R47.2, U9.48 (GPIO41_ADC1)
ROM_A14: R72.2, SW1.1, U2.27 (A14)
ROM_A15: R73.2, SW1.2, U2.1 (A15)
TAPE: R62.2, U9.46 (GPIO39)
TX2+: R49.2, U9.52 (GPIO45_ADC5)
TX2-: R50.2, U9.49 (GPIO44_ADC4)
VSYNC/CLK+: R38.2, R45.2, U9.54 (GPIO47_ADC7)
VSYS_2: C13.1, D13.1 (K), J13.1, R61.2, U10.8 (V+)
/UCLK: C9.1, R21.2, R22.1, U9.43 (GPIO38)

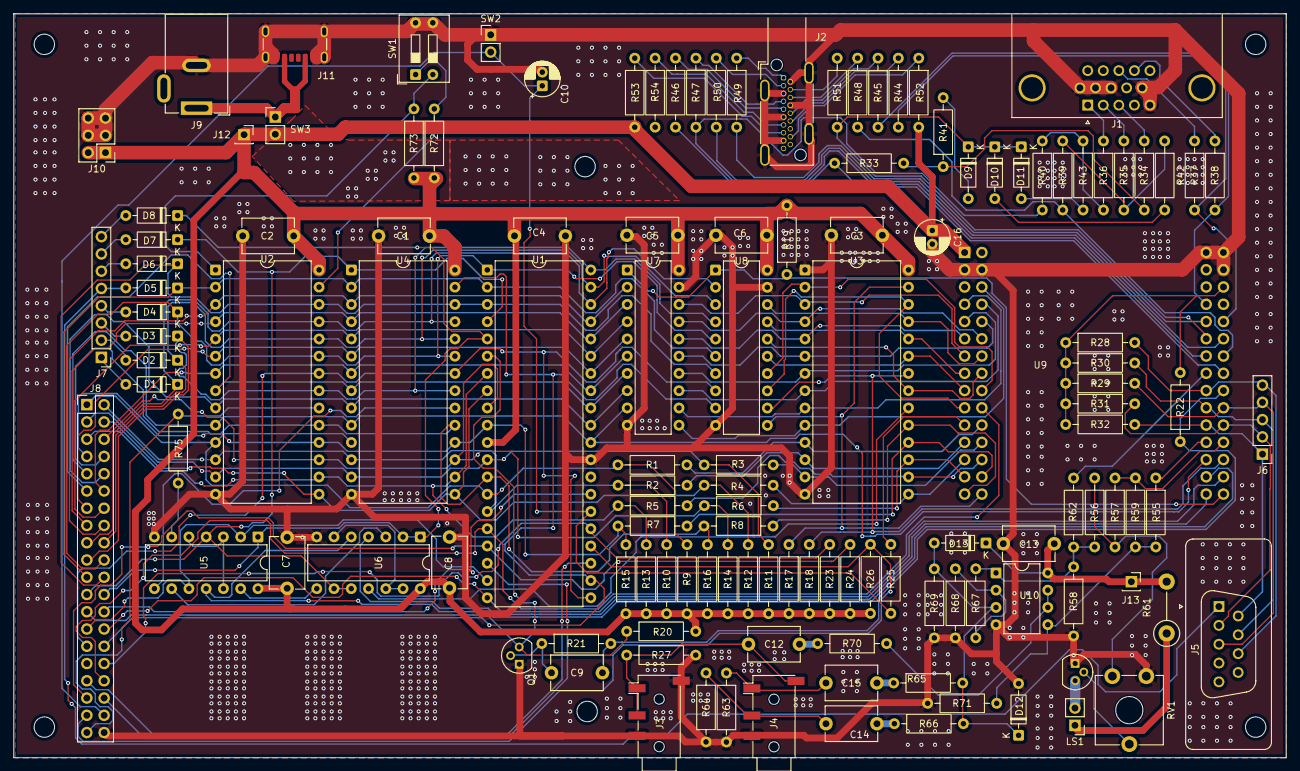
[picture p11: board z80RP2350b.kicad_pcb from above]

Board: 2 copper layers, 187.3 x 109.5 mm, 131 parts (0 on the bottom side), 143 nets.

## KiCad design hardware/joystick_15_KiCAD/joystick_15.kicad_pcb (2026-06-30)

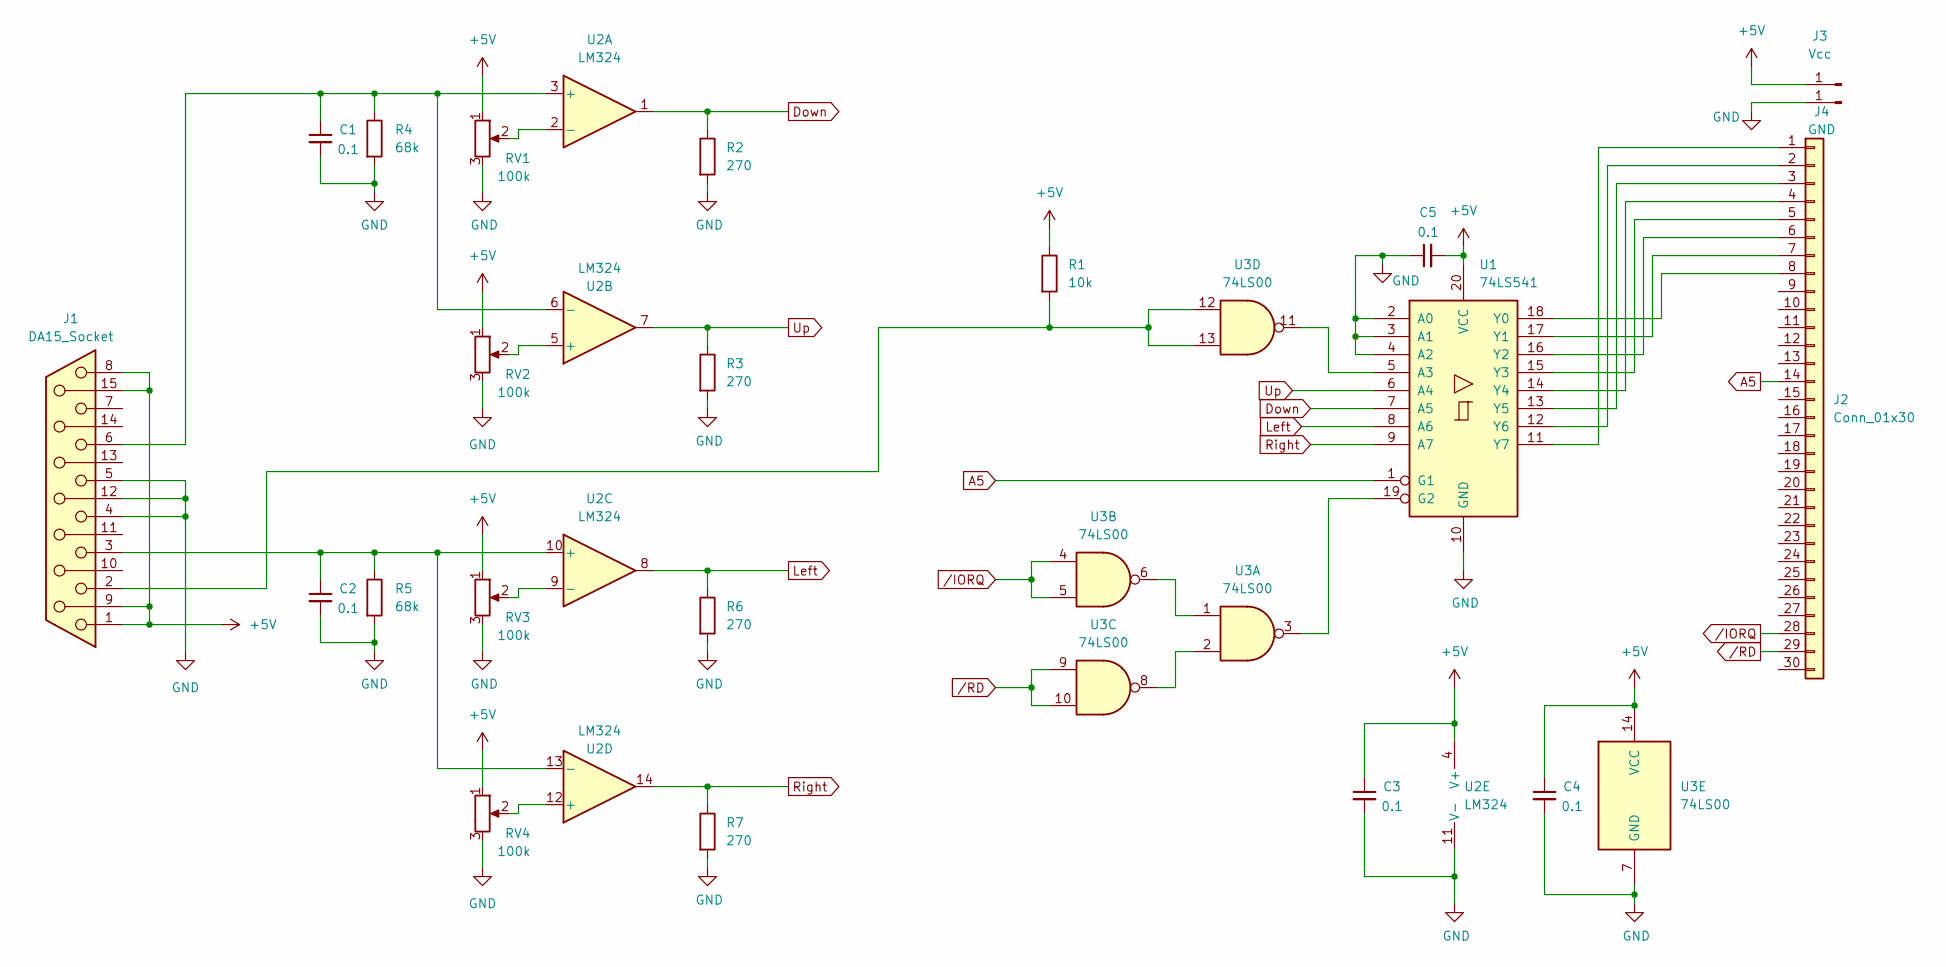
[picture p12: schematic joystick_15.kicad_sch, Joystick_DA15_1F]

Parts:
C1, C2, C3, C4, C5: 0.1; C_Disc_D4.7mm_W2.5mm_P5.00mm
J1: DA15_Socket; DSUB-15_Socket_Horizontal_P2.77x2.84mm_EdgePinOffset7.70mm_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
J2: Conn_01x30; PinSocket_2x15_P2.54mm_Vertical
J3: Vcc; Pin_D1.0mm_L10.0mm
J4: GND; Pin_D1.0mm_L10.0mm
R1: 10k; R_Axial_DIN0207_L6.3mm_D2.5mm_P7.62mm_Horizontal
R2, R3, R6, R7: 270; R_Axial_DIN0207_L6.3mm_D2.5mm_P7.62mm_Horizontal
R4, R5: 68k; R_Axial_DIN0207_L6.3mm_D2.5mm_P7.62mm_Horizontal
RV1, RV2, RV3, RV4: 100k; Potentiometer_Bourns_3296W_Vertical
U1: 74LS541; DIP-20_W7.62mm
U2: LM324; DIP-14_W7.62mm
U3: 74LS00; DIP-14_W7.62mm

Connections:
+5V: C3.1, C4.1, C5.2, J1.1, J1.8, J1.9, J1.15, J3.1, R1.1, RV1.1, RV2.1, RV3.1, RV4.1, U1.20 (VCC), U2.4 (V+), U3.14 (VCC)
A5: J2.14, U1.1 (G1)
Down: R2.1, U1.7 (A5), U2.1
GND: C1.2, C2.2, C3.2, C4.2, C5.1, J1.4, J1.5, J1.12, J4.1, R2.2, R3.2, R4.2, R5.2, R6.2, R7.2, RV1.3, RV2.3, RV3.3, RV4.3, U1.2 (A0), U1.3 (A1), U1.4 (A2), U1.10 (GND), U2.11 (V-), U3.7 (GND)
Left: R6.1, U1.8 (A6), U2.8
unnamed: J1.2, R1.2, U3.12, U3.13
unnamed: J2.1, U1.11 (Y7)
unnamed: J2.2, U1.12 (Y6)
unnamed: J2.3, U1.13 (Y5)
unnamed: J2.4, U1.14 (Y4)
unnamed: J2.5, U1.15 (Y3)
unnamed: J2.6, U1.16 (Y2)
unnamed: J2.7, U1.17 (Y1)
unnamed: J2.8, U1.18 (Y0)
unnamed: U1.5 (A3), U3.11
unnamed: U1.19 (G2), U3.3
unnamed: C1.1, J1.6, R4.1, U2.3 (+), U2.6 (-)
unnamed: RV1.2, U2.2 (-)
unnamed: RV2.2, U2.5 (+)
unnamed: C2.1, J1.3, R5.1, U2.10 (+), U2.13 (-)
unnamed: RV3.2, U2.9 (-)
unnamed: RV4.2, U2.12 (+)
unnamed: U3.1, U3.6
unnamed: U3.2, U3.8
Right: R7.1, U1.9 (A7), U2.14
Up: R3.1, U1.6 (A4), U2.7
/IORQ: J2.28, U3.4, U3.5
/RD: J2.29, U3.9, U3.10

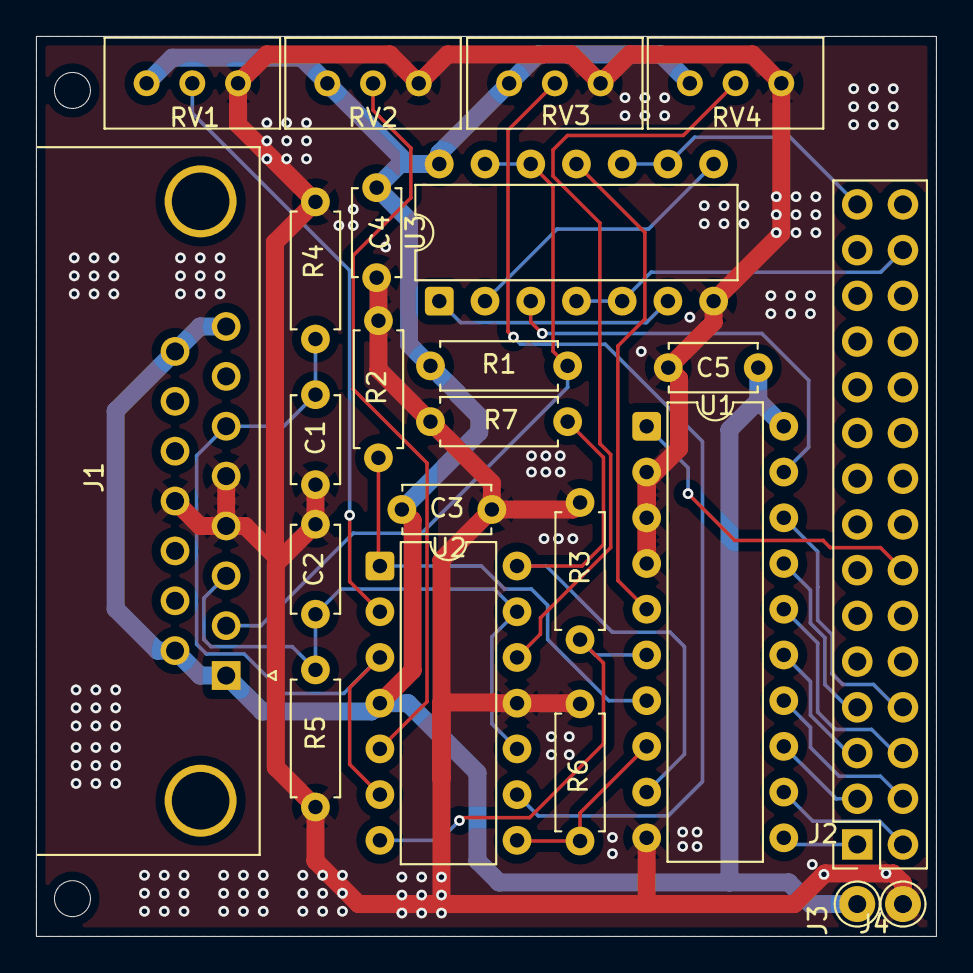
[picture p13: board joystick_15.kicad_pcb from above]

Board: 2 copper layers, 50.0 x 50.0 mm, 23 parts (0 on the bottom side), 28 nets.

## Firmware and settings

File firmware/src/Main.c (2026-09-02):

#include <stdio.h>
#include "hardware/pio.h"
#include "pico/stdlib.h"
#include "hardware/clocks.h"
#include "hardware/dma.h"
#include "pico/multicore.h"
#include "hardware/pwm.h"
#include "Pin_defs.h"

//for 189MHz
#include "MCLK.pio.h"
#include "CPUCLK.pio.h"
#include "IN_FE.pio.h"
#include "OUT_FE.pio.h"

//for 154MHz
#include "MCLK154.pio.h"
#include "CPUCLK154.pio.h"
#include "IN_FE154.pio.h"

//for 189MHz
#include "VGA.pio.h"
#include "activevideo.pio.h"
#include "VRAM_VGA.pio.h"

//for 154MHz
#include "VGA154.pio.h"
#include "activevideo154.pio.h"
#include "VRAM_VGA154.pio.h"

//for 189MHz
#include "INT.pio.h"
#include "Read_frame.pio.h"
#include "Read_line.pio.h"
#include "Read_VRAM.pio.h"

//for 154MHz
#include "INT154.pio.h"
#include "Read_frame154.pio.h"
#include "Read_line154.pio.h"
#include "Read_VRAM154.pio.h"

#define pixel_bytes_count 98304

#define half_border_count 48
#define screen_line_count 256

uint8_t vga_data_array[pixel_bytes_count] = {0};
uint8_t border = 0x7;

uint32_t vram_address = 0;

int ctrl_chan;
int data_chan;
int border_chan;

uint16_t currentline = 0;

struct {uint32_t ctrl; uint32_t len; const char *data; io_wo_32 *write;} control_blocks[4];

uint32_t data_line_ctrl;

void handle_VRAM_read() {
    PIO Read_VRAMpio = pio2;
    uint Read_VRAMsm = 3;
    uint8_t frames = 0;
    while (true) {
        uint32_t display_address = 0;
        for (uint32_t row=0; row<192; row++) {
            uint32_t line_addr = ((row & 0xC0) << 5) | ((row & 0x07) << 8) | ((row & 0x38) << 2);
            uint32_t rowattrbase = 6144+((row >> 3) << 5);
            for (uint8_t pixelbyte = 0; pixelbyte < 32; pixelbyte++) {
                pio_sm_put_blocking(Read_VRAMpio, Read_VRAMsm, line_addr+pixelbyte); 
                uint8_t pixels = pio_sm_get_blocking(Read_VRAMpio, Read_VRAMsm);
                pio_sm_put_blocking(Read_VRAMpio, Read_VRAMsm, rowattrbase+pixelbyte);
                uint8_t attr = pio_sm_get_blocking(Read_VRAMpio, Read_VRAMsm);
                uint8_t paper = (attr >> 3);
                uint8_t ink = attr & 0b00000111 | paper & 0b00001000;
                for (int8_t pixelindex=7; pixelindex>=0; pixelindex--) {
                    uint8_t pixel_bit = (pixels >> pixelindex) & 1;
                    if (pixel_bit ^ ((paper & (frames & 0b00010000)) >> 4)) {
                        vga_data_array[display_address] = ink;
                        vga_data_array[display_address+256] = ink;
                    } else {
                        vga_data_array[display_address] = paper;
                        vga_data_array[display_address+256] = paper;
                    }
                    display_address++;
                }
            }
            display_address+=256;
        }
        frames++;
    }
}

void dma_handler() {
    dma_hw->ints0 = 1u << data_chan;

    if (currentline < 96 || currentline >= 480) {
        control_blocks[1].ctrl = control_blocks[0].ctrl;
        control_blocks[1].data = &border;
    } else {
        control_blocks[1].ctrl = data_line_ctrl;
        control_blocks[1].data = &vga_data_array[vram_address];
        vram_address+=screen_line_count;
    }

    currentline++;
    if (currentline >= 575) {
        currentline = 0;
        vram_address = 0;
    }

    dma_channel_set_read_addr(ctrl_chan, &control_blocks[0], true);    
}

bool VGAconnected() {

    gpio_init(VGA_B); 
    gpio_set_dir(VGA_B, true);
    gpio_put(VGA_B, true); 
    
    sleep_us(1);

    gpio_init(BRIGHT); 
    gpio_set_dir(BRIGHT, false);
    return !gpio_get(BRIGHT); 

}

int main()
{

    bool VGAoutput = VGAconnected();

    if (VGAoutput) {
         set_sys_clock_khz(154000, true);
    } else {
        set_sys_clock_khz(189000, true);    // for HDMI timings
    }

    gpio_init(UCLK); 
    gpio_set_dir(UCLK, true);
    gpio_put(UCLK, true);  // set UCLK = 1 (CLK = 0)

    gpio_init(Z80Reset); // init CPU RESET gpio
    gpio_set_drive_strength(Z80Reset, GPIO_DRIVE_STRENGTH_12MA);
    gpio_set_dir(Z80Reset, true); // direction = OUT
    gpio_put(Z80Reset, false); // set CPU RESET active

    gpio_init(UCS); 
    gpio_set_dir(UCS, true);
    gpio_put(UCS, true);  // set UCS = 1

    gpio_init(UBUS); 
    gpio_set_dir(UBUS, true);
    gpio_put(UBUS, true);  // set UBUS = 1
 
    PIO MCLKpio = pio0;
    uint MCLKsm = 0;
    uint MCLKoffset = 0;

    uint CPUCLKsm = 1;
    uint CPUCLKoffset = 1;

    uint IN_FEsm = 2;
    uint IN_FEoffset = 12;

    uint OUT_FEsm = 3;
    uint OUT_FEoffset = 22;

    PIO VGApio = pio1;

    uint VGA_HSYNCsm = 0;
    uint VGA_VSYNCsm = 1;
    uint VGAoffset = 0;

    uint activevideosm = 2;
    uint activevideooffset = 10;

    uint VRAM_VGAsm = 3;
    uint VRAM_VGAoffset = 22;

    PIO Read_VRAMpio = pio2;

    uint INTsm = 0;
    uint INToffset = 0;

    uint Read_framesm = 1;
    uint Read_frameoffset = 8;
    
    uint Read_linesm = 2;
    uint Read_lineoffset = 15;

    uint Read_VRAMsm = 3;
    uint Read_VRAMoffset = 26;
    
    bool success;
//    hard_assert(success); 
    success = pio_set_gpio_base(MCLKpio, 16);
    success = pio_set_gpio_base(VGApio, 16);
    success = pio_set_gpio_base(Read_VRAMpio, 0);

    if (VGAoutput) {    
        success = pio_add_program_at_offset(MCLKpio, &MCLK154_program, MCLKoffset);
        success = pio_add_program_at_offset(MCLKpio, &CPUCLK154_program, CPUCLKoffset);
        success = pio_add_program_at_offset(MCLKpio, &IN_FE154_program, IN_FEoffset);
        success = pio_add_program_at_offset(MCLKpio, &OUT_FE_program, OUT_FEoffset);

        success = pio_add_program_at_offset(VGApio, &VGA154_program, VGAoffset);    
        success = pio_add_program_at_offset(VGApio, &activevideo154_program, activevideooffset);        
        success = pio_add_program_at_offset(VGApio, &VRAM_VGA154_program, VRAM_VGAoffset);        

        success = pio_add_program_at_offset(Read_VRAMpio, &INT154_program, INToffset);
        success = pio_add_program_at_offset(Read_VRAMpio, &Read_frame154_program, Read_frameoffset);        
        success = pio_add_program_at_offset(Read_VRAMpio, &Read_line154_program, Read_lineoffset);        
        success = pio_add_program_at_offset(Read_VRAMpio, &Read_VRAM154_program, Read_VRAMoffset);    
    } else {
        success = pio_add_program_at_offset(MCLKpio, &MCLK_program, MCLKoffset);
        success = pio_add_program_at_offset(MCLKpio, &CPUCLK_program, CPUCLKoffset);
        success = pio_add_program_at_offset(MCLKpio, &IN_FE_program, IN_FEoffset);
        success = pio_add_program_at_offset(MCLKpio, &OUT_FE_program, OUT_FEoffset);        

        success = pio_add_program_at_offset(VGApio, &VGA_program, VGAoffset);    
        success = pio_add_program_at_offset(VGApio, &activevideo_program, activevideooffset);        
        success = pio_add_program_at_offset(VGApio, &VRAM_VGA_program, VRAM_VGAoffset);        

        success = pio_add_program_at_offset(Read_VRAMpio, &INT_program, INToffset);
        success = pio_add_program_at_offset(Read_VRAMpio, &Read_frame_program, Read_frameoffset);        
        success = pio_add_program_at_offset(Read_VRAMpio, &Read_line_program, Read_lineoffset);        
        success = pio_add_program_at_offset(Read_VRAMpio, &Read_VRAM_program, Read_VRAMoffset);    
    }

    ctrl_chan = dma_claim_unused_channel(true);
    data_chan = dma_claim_unused_channel(true);
    border_chan = dma_claim_unused_channel(true);

    dma_channel_config cb = dma_channel_get_default_config(border_chan);
    channel_config_set_transfer_data_size(&cb, DMA_SIZE_8);
    channel_config_set_read_increment(&cb, false);
    channel_config_set_write_increment(&cb, false);
    channel_config_set_dreq(&cb, DREQ_PIO0_RX3);
    
     dma_channel_configure(
        border_chan,                 // Channel to be configured
        &cb,                        // The configuration we just created
        &border,            // write address (border color)
        &MCLKpio->rxf[OUT_FEsm],          // read address (VRAM_VGA PIO TX FIFO)
        dma_encode_endless_transfer_count(),                    // Number of transfers; in this case each is 1 byte.
        true                     // Start immediately, why not
    );

    dma_channel_config c0 = dma_channel_get_default_config(data_chan);
    channel_config_set_transfer_data_size(&c0, DMA_SIZE_8);
    channel_config_set_write_increment(&c0, false);
    channel_config_set_dreq(&c0, DREQ_PIO1_TX3);                     
    channel_config_set_chain_to(&c0, ctrl_chan);
    channel_config_set_irq_quiet(&c0, true);

    channel_config_set_read_increment(&c0, true);                       
    data_line_ctrl = channel_config_get_ctrl_value(&c0);
    channel_config_set_read_increment(&c0, false);
    control_blocks[0].ctrl = channel_config_get_ctrl_value(&c0);
    control_blocks[1].ctrl = channel_config_get_ctrl_value(&c0);
    control_blocks[2].ctrl = channel_config_get_ctrl_value(&c0);
    control_blocks[3].ctrl = channel_config_get_ctrl_value(&c0);

    control_blocks[0].len = half_border_count;
    control_blocks[1].len = screen_line_count;
    control_blocks[2].len = half_border_count;
    control_blocks[3].len = 0;

    control_blocks[0].data = &border;
    control_blocks[1].data = &border;
    control_blocks[2].data = &border;
    control_blocks[3].data = &border;

    control_blocks[0].write = &VGApio->txf[VRAM_VGAsm];
    control_blocks[1].write = &VGApio->txf[VRAM_VGAsm];    
    control_blocks[2].write = &VGApio->txf[VRAM_VGAsm];    
    control_blocks[3].write = NULL;

    dma_channel_configure(
        data_chan,                 // Channel to be configured
        &c0,                        // The configuration we just created
        &VGApio->txf[VRAM_VGAsm],          // write address (VRAM_VGA PIO TX FIFO)
        &border,            // The initial read address (border color)
        half_border_count,                    // Number of transfers; in this case each is 1 byte.
        false                       // Don't start immediately.
    );

    dma_channel_config c1 = dma_channel_get_default_config(ctrl_chan);  
    channel_config_set_transfer_data_size(&c1, DMA_SIZE_32);            
    channel_config_set_read_increment(&c1, true);                       
    channel_config_set_write_increment(&c1, true);                      
    channel_config_set_ring(&c1, true, 4);

    dma_channel_configure(
        ctrl_chan,                 
        &c1,                       
        &dma_hw->ch[data_chan].al2_ctrl,
        &control_blocks[0],
        4,
        false                       
    );

    dma_channel_set_irq0_enabled(data_chan, true);

    irq_set_exclusive_handler(DMA_IRQ_0, dma_handler);
    irq_set_enabled(DMA_IRQ_0, true);

    if (VGAoutput) {
        CPUCLK154_program_init(MCLKpio, CPUCLKsm, CPUCLKoffset, UCLK, UBUS);

        VGA154_program_init(VGApio, VGA_HSYNCsm, VGAoffset, HSYNC);
        pio_sm_put_blocking(VGApio, VGA_HSYNCsm, 207-1); //hsync high in 7MHz clocks 207
        pio_sm_put_blocking(VGApio, VGA_HSYNCsm, 17-1); // hsync low  in 7MHz clocks

        VGA154_program_init(VGApio, VGA_VSYNCsm, VGAoffset, VSYNC);
        pio_sm_put_blocking(VGApio, VGA_VSYNCsm,  (69888-112*5)*2-1); 
        pio_sm_put_blocking(VGApio, VGA_VSYNCsm, 112*5*2-1); 

        activevideo154_program_init(VGApio, activevideosm, activevideooffset);
        pio_sm_put_blocking(VGApio, activevideosm, 38-1); //39 lines to skip for vertical backporch
        pio_sm_put_blocking(VGApio, activevideosm, 575-1); //576 lines in frame

        VRAM_VGA154_program_init(VGApio, VRAM_VGAsm, VRAM_VGAoffset, VGA_B);
        pio_sm_put_blocking(VGApio, VRAM_VGAsm, 352-1); //352 pixels in line

        INT154_program_init(Read_VRAMpio, INTsm, INToffset, INT);
        pio_sm_put_blocking(Read_VRAMpio, INTsm, 891); //892 (891 = ~14330 T in total before 1st pixel, which is better than 892)

        Read_frame154_program_init(Read_VRAMpio, Read_framesm, Read_frameoffset);
        pio_sm_put_blocking(Read_VRAMpio, Read_framesm, 192-1); //192 lines
        
        Read_line154_program_init(Read_VRAMpio, Read_linesm, Read_lineoffset, UCS, URD);
        Read_VRAM154_program_init(Read_VRAMpio, Read_VRAMsm, Read_VRAMoffset, URD, Y0, Q0);    

        IN_FE154_program_init(MCLKpio, IN_FEsm, IN_FEoffset, Q0, IORQ);
        OUT_FE_program_init(MCLKpio, OUT_FEsm, OUT_FEoffset, CWE, Q0, MIC);

        MCLK154_program_init(MCLKpio, MCLKsm, MCLKoffset);
    } else {

        CPUCLK_program_init(MCLKpio, CPUCLKsm, CPUCLKoffset, UCLK, UBUS);
    
        VGA_program_init(VGApio, VGA_HSYNCsm, VGAoffset, HSYNC);
        pio_sm_put_blocking(VGApio, VGA_HSYNCsm, 800-1-2); //hsync high in 27MHz clocks
        pio_sm_put_blocking(VGApio, VGA_HSYNCsm, 64-1-1); // hsync low in 27MHz clocks

        VGA_program_init(VGApio, VGA_VSYNCsm, VGAoffset, VSYNC);
        pio_sm_put_blocking(VGApio, VGA_VSYNCsm,  534816-1-2); // must be 535680 for 620 active lines, 534816 for 619 lines in 27MHz clocks
        pio_sm_put_blocking(VGApio, VGA_VSYNCsm, 4320-1-1); // VSYNC = low for 5 lines in 27MHz clocks

        activevideo_program_init(VGApio, activevideosm, activevideooffset);
        pio_sm_put_blocking(VGApio, activevideosm, 38-1); //39 lines to skip for vertical backporch
        pio_sm_put_blocking(VGApio, activevideosm, 575-1); //576 lines in frame

        VRAM_VGA_program_init(VGApio, VRAM_VGAsm, VRAM_VGAoffset, VGA_B, DE);
        pio_sm_put_blocking(VGApio, VRAM_VGAsm, 352-1); //352 pixels in line

        INT_program_init(Read_VRAMpio, INTsm, INToffset, INT);
        pio_sm_put_blocking(Read_VRAMpio, INTsm, 891); //892 (891 = ~14330 T in total before 1st pixel, which is better than 892)

        Read_frame_program_init(Read_VRAMpio, Read_framesm, Read_frameoffset);
        pio_sm_put_blocking(Read_VRAMpio, Read_framesm, 192-1); //192 lines

        Read_line_program_init(Read_VRAMpio, Read_linesm, Read_lineoffset, UCS, URD);
        Read_VRAM_program_init(Read_VRAMpio, Read_VRAMsm, Read_VRAMoffset, URD, Y0, Q0);    

        IN_FE_program_init(MCLKpio, IN_FEsm, IN_FEoffset, Q0, IORQ);
        OUT_FE_program_init(MCLKpio, OUT_FEsm, OUT_FEoffset, CWE, Q0, MIC);

        MCLK_program_init(MCLKpio, MCLKsm, MCLKoffset);
    }

// set up HDMI/DVI pixel clock:    

    gpio_set_function(PXLCLK, GPIO_FUNC_PWM);

    uint slice = pwm_gpio_to_slice_num(PXLCLK);
    uint chan  = pwm_gpio_to_channel(PXLCLK);

    pwm_config cfg = pwm_get_default_config();

    pwm_config_set_clkdiv_int_frac(&cfg, 1, 0); 
    pwm_config_set_wrap(&cfg, 6); // 189000000/(7*(1+0/16)) = 27,000,000Hz
    pwm_init(slice, &cfg, false);

    pwm_set_chan_level(slice, chan, 3);  

    multicore_launch_core1(handle_VRAM_read); // core1 to handle video RAM read process 

    dma_start_channel_mask((1u << ctrl_chan));    

    if (!VGAoutput) pwm_set_enabled(slice, true); // start 27MHz pixel clock if HDMI/DVI

    MCLKpio->ctrl = 0b101111111110000111100001111; // start everything at once

    sleep_ms(3245); // wait for VGA monitor to respond

    gpio_put(Z80Reset, true); // set CPU RESET inactive

    while (true) {tight_loop_contents();} // forever...

}

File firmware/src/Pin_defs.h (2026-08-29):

#define Y0 0
#define INT 14
#define Z80Reset 15

#define Q0 16
#define Q1 17
#define Q2 18
#define Q3 19
#define Q4 20
#define Q5 21
#define Q6 22
#define Q7 23

#define CWE 24
#define UCS 25
#define UBUS 26
#define VRAMCS 27
#define IORQ 28
#define A0 29
#define URD 30
#define MIC 31
#define EAR 32
#define KB1 33
#define KB2 34
#define KB3 35
#define KB4 36
#define KB5 37
#define UCLK 38
#define TAPE 39

#define VGA_B 40
#define VGA_R 41
#define VGA_G 42
#define BRIGHT 43
#define DE 44
#define PXLCLK 45
#define HSYNC 46
#define VSYNC 47

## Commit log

2026-06-30 KiCAD project for Joystock interface added
    [joystick_15.kicad_pcb, joystick_15.kicad_sch]
2026-07-01 z80rp2350b KiCAD project added, pictures updated
    [z80RP2350b.kicad_pcb, z80RP2350b.kicad_sch]
2026-08-29 HDMI Kicad project and photos added
    [HDMITransmitter.kicad_pcb, HDMITransmitter.kicad_sch]
